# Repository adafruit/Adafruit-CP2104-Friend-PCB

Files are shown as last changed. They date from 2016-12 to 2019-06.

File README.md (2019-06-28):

## Adafruit CP2104 Friend PCB

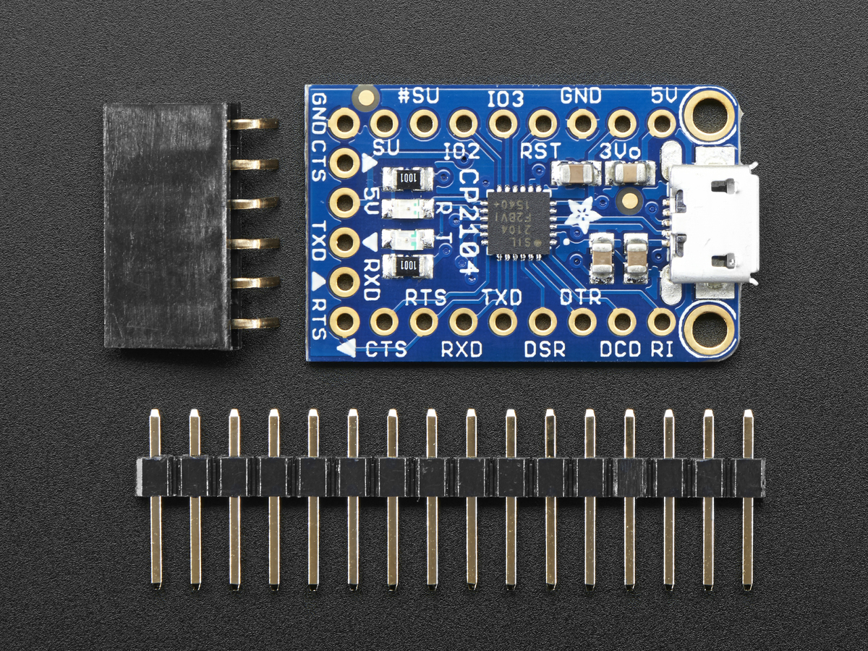
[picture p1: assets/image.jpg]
<a href="http://www.adafruit.com/products/3309"><br/>
Click here to purchase one from the Adafruit shop</a>

PCB files for the Adafruit CP2104 Friend. Format is EagleCAD schematic and board layout
* https://www.adafruit.com/product/3309

### Description

Long gone are the days of parallel ports and serial ports. Now the USB port reigns supreme! But USB is hard, and you just want to transfer your every-day serial data from a microcontroller to computer. What now? Enter the Adafruit CP2104 Friend!

This is a high-quality CP2104 USB-Serial chip that can upload code at a blistering 2Mbit/s for fast development time. It also has auto-reset for Arduino/ATmega328 boards so no noodling with pins and reset button pressings. The CP2104 has better driver support than the CH340 and can do very high speeds, and variable speeds without stability issues. Compared to the FT232RL and FT231X, the CP2104 has the same capabilities or better, at a great price! It even has the RX/TX LEDs to help you debug your data, they'll blink when the chip receives/transmits data.

By default, we've set it up so that it matches our FTDI cables. The 6th pin is RTS, the power wire is +5V and the signal levels are 3.3V (they are 5V compliant, and should work in the vast majority of 3.3V and 5V signal systems). Works excellently with any Arduino, ESP8266, ESP32 or any other microcontroller that uses an 'FTDI port' for communications and upload. You can also purchase a 6-pin extension cable from us, which will let you rearrange the wire order.

There's also a full collection of all the modem control pins you may need on the side, in case you need the DTR, RI, DSR, etc. pins.

### License

Adafruit invests time and resources providing this open source design, please support Adafruit and open-source hardware by purchasing products from [Adafruit](https://www.adafruit.com)!

Designed by Limor Fried/Ladyada for Adafruit Industries.

Creative Commons Attribution/Share-Alike, all text above must be included in any redistribution. See license.txt for additional details.

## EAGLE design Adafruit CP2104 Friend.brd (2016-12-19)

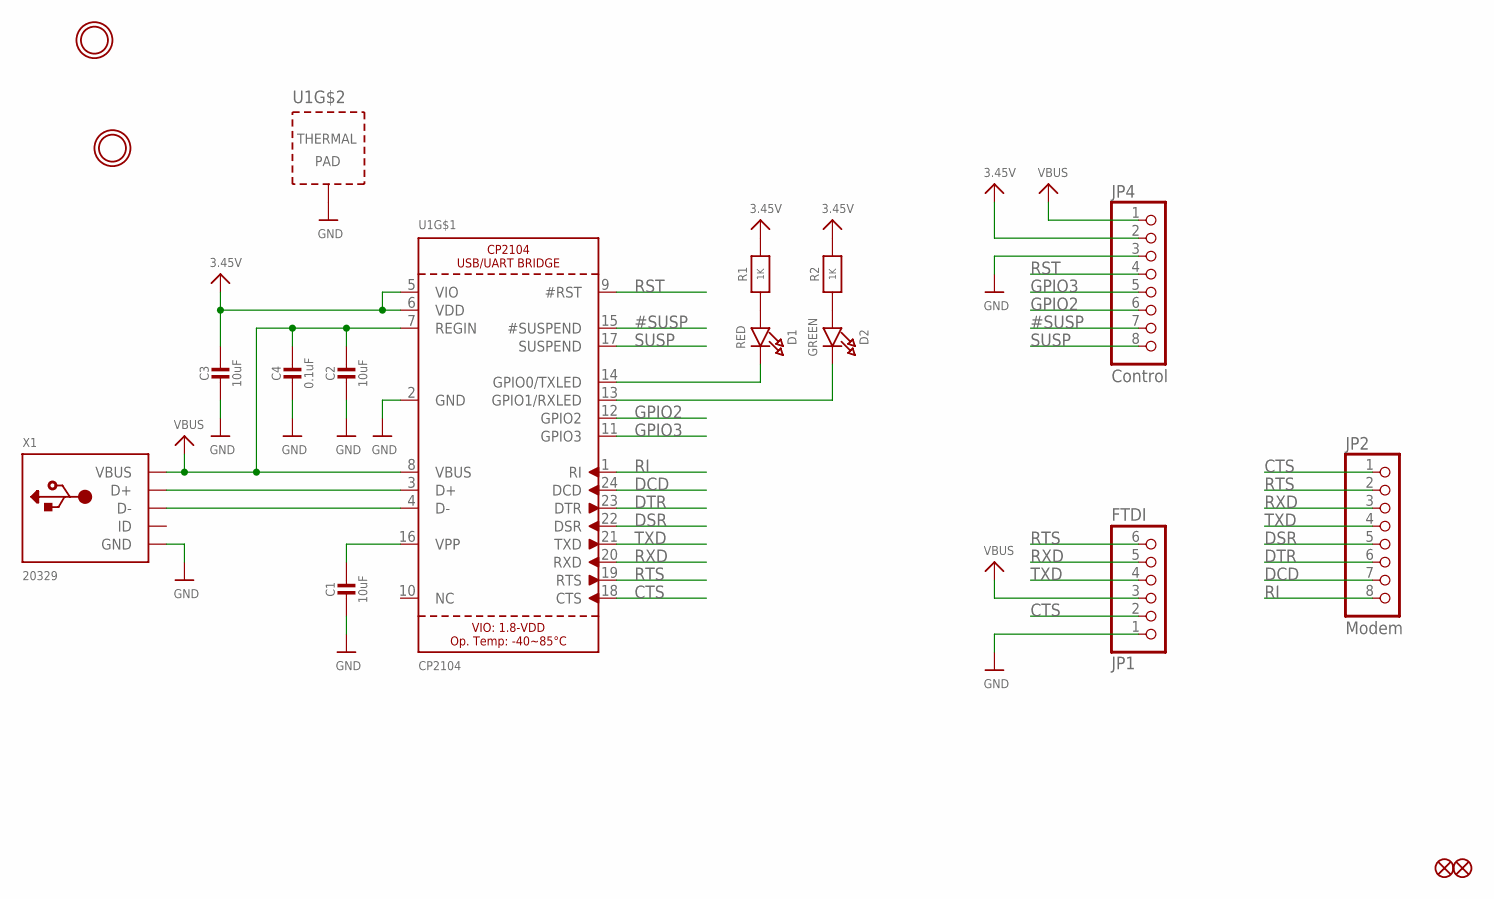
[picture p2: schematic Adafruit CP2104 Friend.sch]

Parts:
C1, C2, C3: 10uF; 0805-NO
C4: 0.1uF; 0805-NO
D1: RED; CHIPLED_0805_NOOUTLINE
D2: GREEN; CHIPLED_0805_NOOUTLINE
FID1, FID2: FIDUCIAL""; FIDUCIAL_1MM
JP1: FTDI; 1X06_ROUND_76
JP2: Modem; 1X08_ROUND_70
JP4: Control; 1X08_ROUND_70
R1, R2: 1K; 0805-NO
U1: CP2104; QFN24_4MM_SMSC
U$18, U$19: MOUNTINGHOLE2.0; MOUNTINGHOLE_2.0_PLATED
X1: 20329; 4UCONN_20329_V2

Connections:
3.3V: C3.1, JP4.2, R1.2, R2.2, U1.5 (VIO), U1.6 (VDD)
#SUSP: JP4.7, U1.15 (#SUSPEND)
CTS: JP1.2, JP2.1, U1.18 (CTS)
DCD: JP2.7, U1.24 (DCD)
DSR: JP2.5, U1.22 (DSR)
DTR: JP2.6, U1.23 (DTR)
GND: C1.2, C2.2, C3.2, C4.2, JP1.1, JP4.3, U1.2 (GND), U1.THERM (TP), X1.BASE@1 (GND), X1.BASE@2 (GND), X1.GND, X1.SPRT@1 (GND), X1.SPRT@2 (GND), X1.SPRT@3 (GND), X1.SPRT@4 (GND)
GPIO2: JP4.6, U1.12 (GPIO2)
GPIO3: JP4.5, U1.11 (GPIO3)
unnamed: D1.A, R1.1
unnamed: U1.3 (D+), X1.D+
unnamed: U1.4 (D-), X1.D-
unnamed: C1.1, U1.16 (VPP)
unnamed: D2.A, R2.1
unnamed: D1.C, U1.14 (GPIO0/TXLED)
unnamed: D2.C, U1.13 (GPIO1/RXLED)
RI: JP2.8, U1.1 (RI)
RST: JP4.4, U1.9 (#RST)
RTS: JP1.6, JP2.2, U1.19 (RTS)
RXD: JP1.5, JP2.3, U1.20 (RXD)
SUSP: JP4.8, U1.17 (SUSPEND)
TXD: JP1.4, JP2.4, U1.21 (TXD)
VBUS: C2.1, C4.1, JP1.3, JP4.1, U1.7 (REGIN), U1.8 (VBUS), X1.VBUS

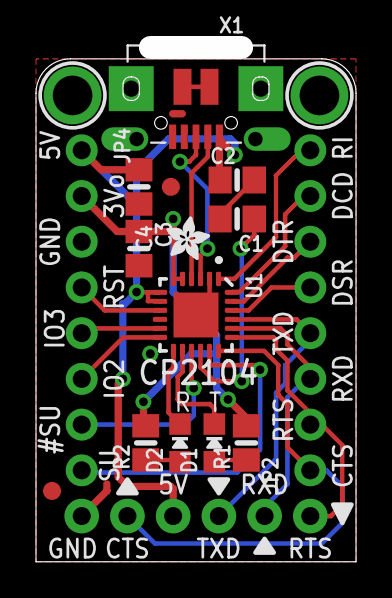
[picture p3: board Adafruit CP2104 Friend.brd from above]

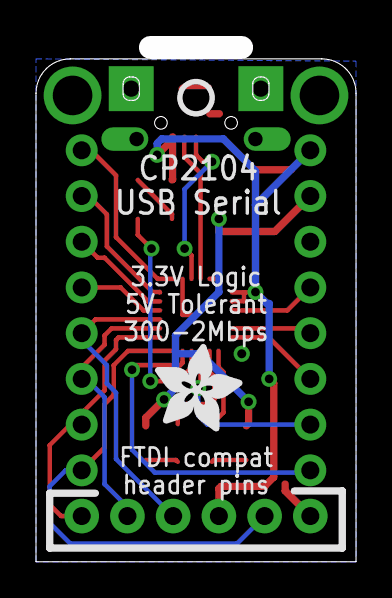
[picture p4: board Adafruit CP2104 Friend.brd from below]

Board: 2 copper layers, 17.8 x 28.6 mm, 20 parts (2 on the bottom side), 23 nets.

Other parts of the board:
U$8: ADAFRUIT_2.5MM
U$17: PCBFEAT-REV-040
U$22: ADAFRUIT_5MM

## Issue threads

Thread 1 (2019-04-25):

Eagle Library

32teeth, 2019-04-25:
Looking for microbuilder.lbr

```
device: CP2104
footprint: QFN24_4MM_SMSC
library: microbuilder
```
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

ladyada, 2019-04-25:
its not public, you can extract library items or copy and paste them to your schematic

Closed 2019-04-25.

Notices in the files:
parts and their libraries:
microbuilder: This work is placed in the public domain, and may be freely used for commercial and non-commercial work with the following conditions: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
